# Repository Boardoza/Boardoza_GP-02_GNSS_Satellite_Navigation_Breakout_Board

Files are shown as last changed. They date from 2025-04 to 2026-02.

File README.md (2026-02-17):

# Boardoza GP-02 BDS/GNSS Multi-Mode Navigation Receiver Breakout Board

The **Boardoza GP-02** is a high-performance **satellite navigation breakout board** featuring the GP-02 SOC, which supports **multi-mode positioning systems** including **BeiDou (BDS)**, **GPS**, and **GLONASS**. It is designed to provide **accurate and reliable geolocation data**, even in challenging signal environments, making it ideal for applications such as **automotive navigation**, **asset tracking**, and **outdoor robotics**.

This module offers **TTL-level UART communication**, making it easy to interface with microcontrollers, and features **low power consumption**, making it highly suitable for battery-powered systems. Its compact design and integrated RF front-end simplify integration in space-constrained projects.

## [Click here to purchase!](https://www.ozdisan.com/maker-and-iot-products/boardoza/boardoza-modules/BOARDOZA-GP-02/1206509)

|Front Side|Back Side|
|:---:|:---:|
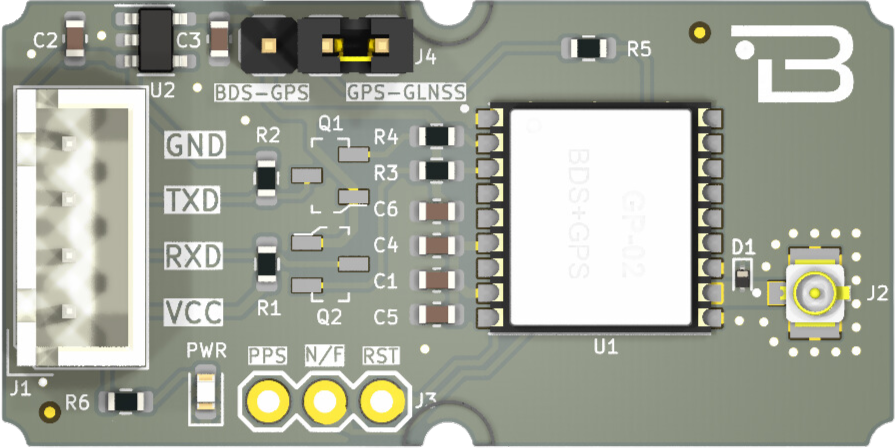
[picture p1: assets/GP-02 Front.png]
GP-02 Front
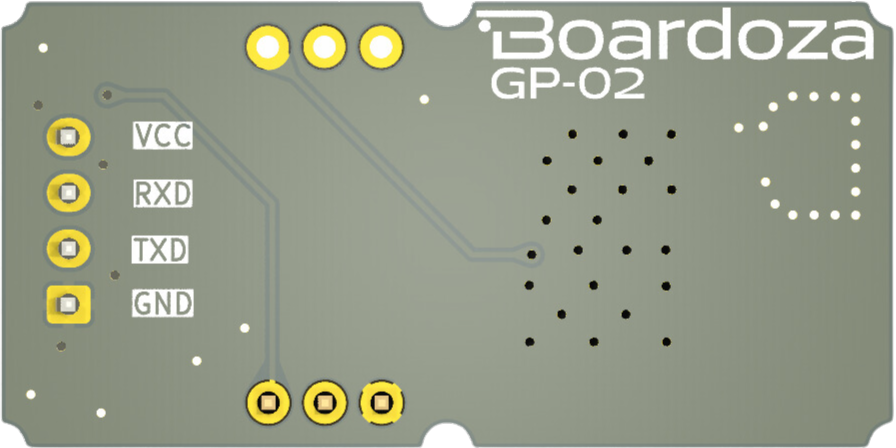
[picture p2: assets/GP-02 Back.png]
GP-02 Back
| | |

---

## Key Features

- **Multi-Mode Satellite Support:** Simultaneous support for BeiDou, GPS, and GLONASS systems ensures broad global coverage and enhanced positioning accuracy.
- **Integrated RF Front-End:** Compact SOC design includes signal processing and antenna interface for superior reception in a small footprint.
- **Low Power Design:** Operates efficiently from 3.3V or 5V sources; ideal for portable devices.
- **Simple TTL UART Communication:** Easily integrates with microcontrollers for real-time geolocation data exchange.
- **Mode Selection via Jumper Pins:** Configure BDS+GPS or GPS+GLONASS modes via J4 jumper configuration.

---

## Technical Specifications

**Model:** Ai Thinker GP-02  
**Voltage Input Type:** 4-pin 2.50mm header  
**Input Voltage:** 5V or 1S Li-Ion Battery (3.3V)  
**Functions:** BDS/GNSS Multi-Mode Navigation Receiver SOC  
**Communication Interface:** UART (TTL Level)  
**Connector Voltage Level:** 3.3V (J3, J4)  
**Operating Temperature:** -40°C ~ +85°C  
**Board Dimensions:** 20mm x 40mm  

---

## Board Pinout

### ( J1 ) UART Communication & Power

| Pin Number | Pin Name | Description |
|:---:|:---:|---|
| 1 | VCC | Power Supply |
| 2 | RX | Received Data Pin |
| 3 | TX | Transmitted Data Pin |
| 4 | GND | Ground |

### ( J3 ) GNSS Control & Timing

| Pin Number | Pin Name | Description |
|:---:|:---:|---|
| 1 | PPS | Time pulse signal output |
| 2 | N/F | Shutdown control (active LOW, internal pull-up) |
| 3 | RST | External reset input (leave unconnected) |

### ( J4 ) GNSS System Selection Jumper

| Pin Combination | Mode | Description |
|:---:|---|---|
| 1–2 | BDS + GPS | Jumper connects IO to HIGH (via VCC) |
| 2–3 | GPS + GLONASS | Jumper connects IO to GND (LOW state) |

> **Note:** J4 is a clever use of hardware jumper to select GNSS mode. When middle pin floats (no jumper), the module defaults to BDS + GPS.

---

## Board Dimensions

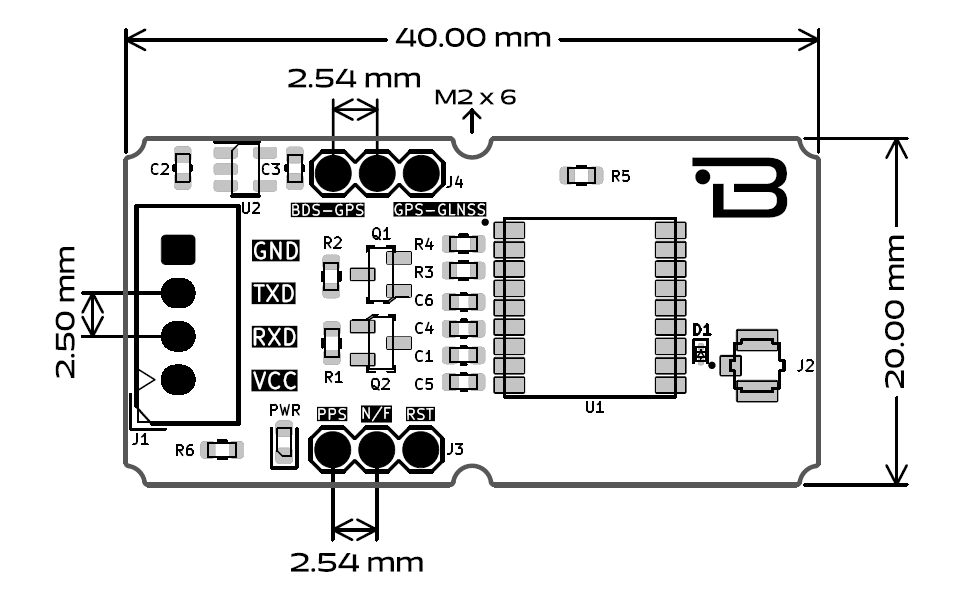
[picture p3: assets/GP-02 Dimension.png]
GP-02 Dimension


---

## Compatible Antennas

For optimal satellite reception and stable positioning performance, it is strongly recommended to use a properly tuned **active GNSS antenna** compatible with the **L1 band**.

Since the GP-02 supports **GPS (1575.42 MHz L1), BeiDou B1 (1561.098 MHz), and GLONASS L1 (~1602 MHz)**, the antenna must cover the **1559–1606 MHz frequency range** to ensure reliable multi-constellation tracking.

An active antenna with an integrated **Low Noise Amplifier (LNA)** significantly improves signal acquisition time, enhances positioning accuracy, and maintains stable performance in weak-signal environments such as urban areas, dense foliage, or partially obstructed outdoor spaces.

Using a properly matched antenna also reduces signal loss and improves receiver sensitivity.

[Recommended Antenna: Active GNSS L1 Antenna (GPS / BDS / GLONASS)  3V–5V with SMA Connector](https://www.ozdisan.com/p/rf-antenler-660/sunnyway-rf-swg003-sw19019ib93-1207541)

**Key Antenna Characteristics:**

- **Frequency Range:** 1559–1606 MHz (L1 Band)  
- **Center Frequencies:** 1.559 / 1.575 / 1.602 GHz  
- **Gain:** 2.13 dBi (1561 MHz), 2.11 dBi (1575 MHz), 2.91 dBi (1602 MHz)   
- **GNSS Support:** GPS, BeiDou, GLONASS, GALILEO
- **Type:** Active patch antenna with integrated LNA
- **Operating Voltage:** 3V–5V (bias powered)
- **Connector Type:** IPEX MHF1
- **Impedance:** 50Ω

>  **Important:** Always connect the antenna before powering the module. Operating the GNSS receiver without a connected antenna may degrade RF performance and potentially damage the RF front-end.

---

## Step Files

[Boardoza GP-02.step](./assets/Boardoza%20GP-02%20Step.step)

---

## Datasheet

[Boardoza GP-02 Datasheet.pdf](./assets/GP-02%20Datasheet.pdf)

---

## Version History

- V1.0.0 - Initial Release

---

## Support

- If you have any questions or need support, please contact <support@boardoza.com>

---

## License

Shield: [][cc-by-sa]

This work is licensed under a [Creative Commons Attribution-ShareAlike 4.0 International License][cc-by-sa].

[][cc-by-sa]

[cc-by-sa]: http://creativecommons.org/licenses/by-sa/4.0/
[cc-by-sa-image]: https://licensebuttons.net/l/by-sa/4.0/88x31.png
[cc-by-sa-shield]: https://img.shields.io/badge/License-CC%20BY--SA%204.0-lightgrey.svg

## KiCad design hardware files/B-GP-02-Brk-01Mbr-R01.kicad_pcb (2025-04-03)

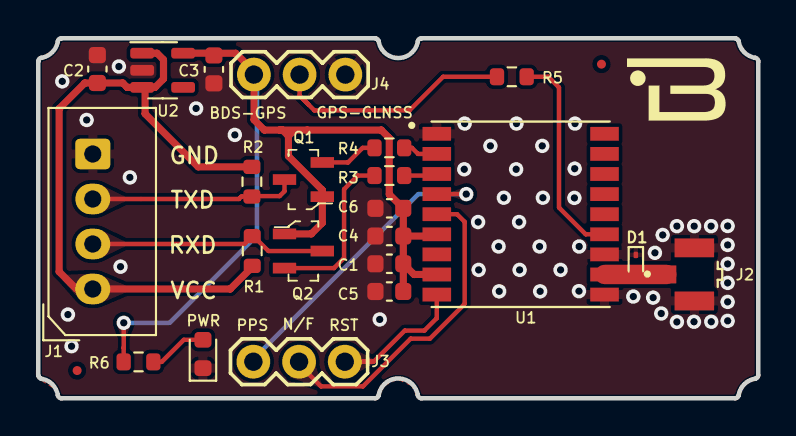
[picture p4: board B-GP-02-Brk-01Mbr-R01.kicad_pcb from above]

Board: 2 copper layers, 40.0 x 20.0 mm, 22 parts (0 on the bottom side), 16 nets.

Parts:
C1, C2, C3: 1uF; C_0603_1608Metric
C4: 820pF; C_0603_1608Metric
C5: 10uF; C_0603_1608Metric
C6: 100nF; C_0603_1608Metric
D1: SZESD9101P2T5G; D_SOD-923
J1: MOLEX_CONNECTOR_1X4; 2317-04S_1x04_P2.50mm_Vertical
J2: 321A-331251; IPEX_20279-001E-03
J3, J4: CONN_03; 1X03
PWR: LED POWER; LED_0603_1608Metric
Q1, Q2: 2N7002_R1_00001; SOT-23-3
R1, R2, R6: 10K; R_0603_1608Metric
R3, R4, R5: 22; R_0603_1608Metric
U1: GP-02; GPS-02
U2: TLV73333PDBVR; SOT-23-5

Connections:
+3V3: C1.2, C3.1, C4.2, C5.2, C6.1, J4.3, Q1.1 (G), Q2.1 (G), R6.1, U1.6 (VRTC), U1.8 (3V3), U2.5 (OUT)
GND: C1.1, C2.2, C3.2, C4.1, C5.1, C6.2, D1.1 (K), J1.4, J2.2, J2.3, J4.1, PWR.1 (K), U1.1 (GND), U1.10 (GND), U1.12 (GND), U2.2 (GND)
IO8: J4.2, R5.2
unnamed: D1.2 (A), J2.1, U1.11 (RF)
unnamed: PWR.2 (A), R6.2
unnamed: Q1.2 (S), R4.2
unnamed: Q2.2 (S), R3.1
unnamed: R5.1, U1.13 (IO8)
unnamed: R3.2, U1.3 (RX0)
unnamed: R4.1, U1.2 (TX0)
N/F: J3.2, U1.5 (N/F)
PPS: J3.1, U1.4 (PPS)
RST: J3.3, U1.9 (RST)
RXD: J1.2, Q2.3 (D), R1.2
TXD: J1.3, Q1.3 (D), R2.2
VCC: C2.1, J1.1, R1.1, R2.1, U2.1 (IN), U2.3 (EN)

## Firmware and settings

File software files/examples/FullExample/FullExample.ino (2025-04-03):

#include <GP02.h>
#include <SoftwareSerial.h>
/*
   This sample code demonstrates the normal use of a GP02 (GP02) object.
   It requires the use of SoftwareSerial, and assumes that you have a
   4800-baud serial GPS device hooked up on pins 4(rx) and 3(tx).
*/
static const int RXPin = 16, TXPin = 17;
static const uint32_t GPSBaud = 9600;

// The GP02 object
GP02 gps;

// The serial connection to the GPS device
SoftwareSerial ss(RXPin, TXPin);


// This custom version of delay() ensures that the gps object
// is being "fed".
static void smartDelay(unsigned long ms)
{
  unsigned long start = millis();
  do 
  {
    while (ss.available())
      gps.encode(ss.read());
  } while (millis() - start < ms);
}

static void printFloat(float val, bool valid, int len, int prec)
{
  if (!valid)
  {
    while (len-- > 1)
      Serial.print('*');
    Serial.print(' ');
  }
  else
  {
    Serial.print(val, prec);
    int vi = abs((int)val);
    int flen = prec + (val < 0.0 ? 2 : 1); // . and -
    flen += vi >= 1000 ? 4 : vi >= 100 ? 3 : vi >= 10 ? 2 : 1;
    for (int i=flen; i<len; ++i)
      Serial.print(' ');
  }
  smartDelay(0);
}

static void printInt(unsigned long val, bool valid, int len)
{
  char sz[32] = "*****************";
  if (valid)
    sprintf(sz, "%ld", val);
  sz[len] = 0;
  for (int i=strlen(sz); i<len; ++i)
    sz[i] = ' ';
  if (len > 0) 
    sz[len-1] = ' ';
  Serial.print(sz);
  smartDelay(0);
}

static void printDateTime(GP02Date &d, GP02Time &t)
{
  if (!d.isValid())
  {
    Serial.print(F("********** "));
  }
  else
  {
    char sz[32];
    sprintf(sz, "%02d/%02d/%02d ", d.month(), d.day(), d.year());
    Serial.print(sz);
  }
  
  if (!t.isValid())
  {
    Serial.print(F("******** "));
  }
  else
  {
    char sz[32];
    sprintf(sz, "%02d:%02d:%02d ", t.hour(), t.minute(), t.second());
    Serial.print(sz);
  }

  printInt(d.age(), d.isValid(), 5);
  smartDelay(0);
}

static void printStr(const char *str, int len)
{
  int slen = strlen(str);
  for (int i=0; i<len; ++i)
    Serial.print(i<slen ? str[i] : ' ');
  smartDelay(0);
}


void setup()
{
  Serial.begin(115200);
  ss.begin(GPSBaud);

  Serial.println(F("FullExample.ino"));
  Serial.println(F("An extensive example of many interesting GP02 features"));
  Serial.print(F("Testing GP02 library v. ")); Serial.println(GP02::libraryVersion());
  Serial.println(F("by Mikal Hart"));
  Serial.println();
  Serial.println(F("Sats HDOP  Latitude   Longitude   Fix  Date       Time     Date Alt    Course Speed Card  Distance Course Card  Chars Sentences Checksum"));
  Serial.println(F("           (deg)      (deg)       Age                      Age  (m)    --- from GPS ----  ---- to London  ----  RX    RX        Fail"));
  Serial.println(F("----------------------------------------------------------------------------------------------------------------------------------------"));
}

void loop()
{
  static const double LONDON_LAT = 51.508131, LONDON_LON = -0.128002;

  printInt(gps.satellites.value(), gps.satellites.isValid(), 5);
  printFloat(gps.hdop.hdop(), gps.hdop.isValid(), 6, 1);
  printFloat(gps.location.lat(), gps.location.isValid(), 11, 6);
  printFloat(gps.location.lng(), gps.location.isValid(), 12, 6);
  printInt(gps.location.age(), gps.location.isValid(), 5);
  printDateTime(gps.date, gps.time);
  printFloat(gps.altitude.meters(), gps.altitude.isValid(), 7, 2);
  printFloat(gps.course.deg(), gps.course.isValid(), 7, 2);
  printFloat(gps.speed.kmph(), gps.speed.isValid(), 6, 2);
  printStr(gps.course.isValid() ? GP02::cardinal(gps.course.deg()) : "*** ", 6);

  unsigned long distanceKmToLondon =
    (unsigned long)GP02::distanceBetween(
      gps.location.lat(),
      gps.location.lng(),
      LONDON_LAT, 
      LONDON_LON) / 1000;
  printInt(distanceKmToLondon, gps.location.isValid(), 9);

  double courseToLondon =
    GP02::courseTo(
      gps.location.lat(),
      gps.location.lng(),
      LONDON_LAT, 
      LONDON_LON);

  printFloat(courseToLondon, gps.location.isValid(), 7, 2);

  const char *cardinalToLondon = GP02::cardinal(courseToLondon);

  printStr(gps.location.isValid() ? cardinalToLondon : "*** ", 6);

  printInt(gps.charsProcessed(), true, 6);
  printInt(gps.sentencesWithFix(), true, 10);
  printInt(gps.failedChecksum(), true, 9);
  Serial.println();
  
  smartDelay(1000);

  if (millis() > 5000 && gps.charsProcessed() < 10)
    Serial.println(F("No GPS data received: check wiring"));
}
